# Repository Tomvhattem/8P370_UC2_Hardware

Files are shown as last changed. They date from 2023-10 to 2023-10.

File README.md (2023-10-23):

# 8P370_UC2_Hardware
This Repository contains several new files and adjusted files made for the UC2 System and the openflexure delta stage for use in the CBL Microscopy course at the TU/e at the courtesy of N4N Group. For questions you can email me at: t.c.v.hattem@student.tue.nl

## Credits and useful links
These adaptation are based on the original files of two open source project UC2 and Openflexure, please check out their respective websites for more information.

- **UC2 Hardware**: Original ImSwitch.
  - Repository: [UC2 General GitHub Repository](https://github.com/openUC2/UC2-GIT)
  - Website: [UC2 Website](https://openuc2.com/)

- **Openflexure Hardware**: .
  - Website: [Openflexure Website]([https://openuc2.com/](https://openflexure.org/))

- **N4N Lab**: Supporting Research Group
  - Website: [n4nlab.eu](https://www.n4nlab.eu/)

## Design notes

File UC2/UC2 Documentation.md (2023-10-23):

# UC2 Add-ons and Custimizations

### Z-Stage
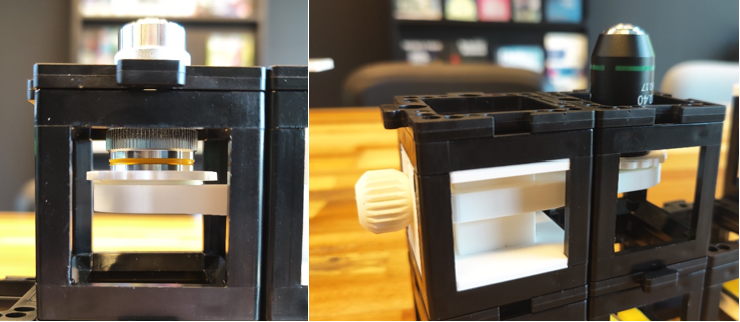
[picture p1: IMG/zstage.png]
 <br>
The original Z-stage https://github.com/openUC2/UC2-GIT/tree/master/CAD/ASSEMBLY_CUBE_Z-STAGE_mechanical is relatively prone to breaking. The manual knob was often very hard to use, therefore the z-stage was redesigned. It requires 2 cubes of space and has two adjustments. A large rough adjustment, by sliding the whole part up or down and tightening with the knob. The objective lense is screwed into a printed screw. The printed part can be rotated for fine adjustments. Printing in ABS has nicer tolerances, especially for the screw part. A combination of all PLA but screw in ABS or the other way around also works nicely. 
With the redesigned manual Z-stage a simple smartphone microscope is built for verification. See https://uc2configurator.netlify.app/ APP_SIMPLE-Smartphone_Microscope <br>

#Heat Inserts
Heat inserts make sure that you can tighten the design for more than once, when only using abs or pla it can quickly be overturned. To ensure longevity of the design heat inserts are used.
Never used heat inserts? Then continue reading… The screw hole at the red arrow in figure 5 is designed for an brass heat insert. 
The brass heat inserts can be pushed into the design from outside into the print with a soldering iron. Makes sure that the insert is straight, you can make sure it is by inserting a long bolt and reapplying heat and straightening the bolt. 
M3 heat inserts are used. They exist in several lengths, they should not be longer than 5.5 [mm]. The Hole is a little bit larger 3.5mm to make sure they fit but do not have excess material pushed into the design. It should be flush with the outside of the print. <br>

<div style="display: flex;">
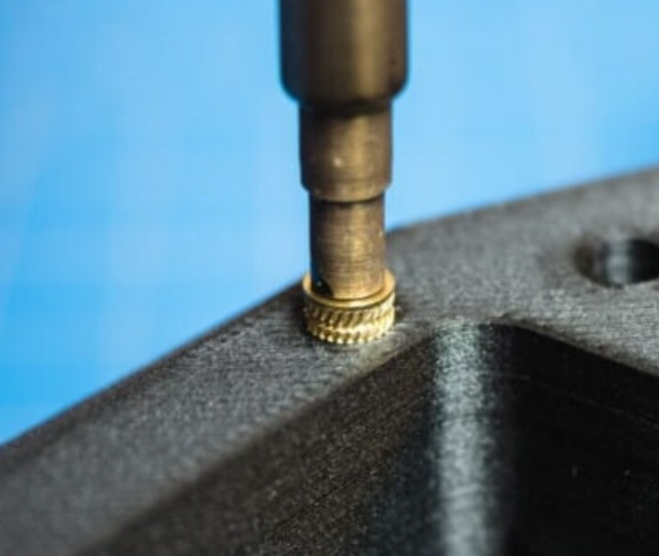
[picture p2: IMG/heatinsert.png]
Heat Insert
    
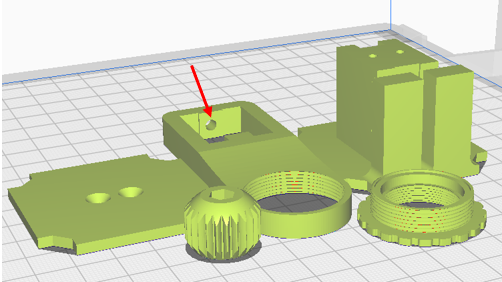
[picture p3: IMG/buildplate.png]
    
</div>

## Insert for Light-Sensitive Setups:
The light-sensitive setup includes a specialized insert designed to block external light sources and prevent light leakage during fluorescence microscopy. Open the cube to insert the 3d printed part. This was designed and tested with ABS, PLA results may vary due to different tolerances. Also depends on the used setup and printer. 

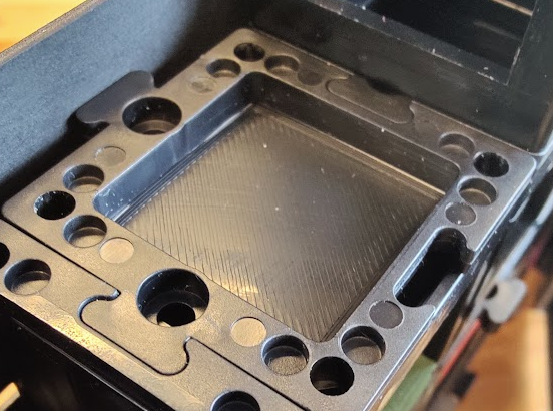
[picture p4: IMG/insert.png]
Insert


## Cardboard Enclosure
The microscope setup includes a custom cardboard enclosure that provides protection and stability for the components. Follow the instructions below for cutting and assembling the cardboard enclosure:

### Assembly Steps:
1. **Cutting the Cardboard:**
   - Depending on your setup measure and draw out the different pieces required to enclose your setup.
   - Ensure precise cutting for accurate fitting of the enclosure components.

2. **Corner Piece Connection:**
   - Use the 3D printed corner pieces to connect the cardboard panels securely.
   - Align the corner pieces with the corresponding corners of the cardboard pieces.
   - Insert the cardboard edges into the slots of the corner pieces.

3. **Setup the Microscope:**
   - Place the microscope inside the assembled cardboard enclosure, ensuring it fits snugly and is properly centered. It might be required to first insert the microscope setup while assembling the cardboard pieces.

4. **Use inserts in critical places:**
   - The insert cover discussed in the previous paragraph might be required in the inside of the microscope since the setup often requires sample and laser to be quite close. 

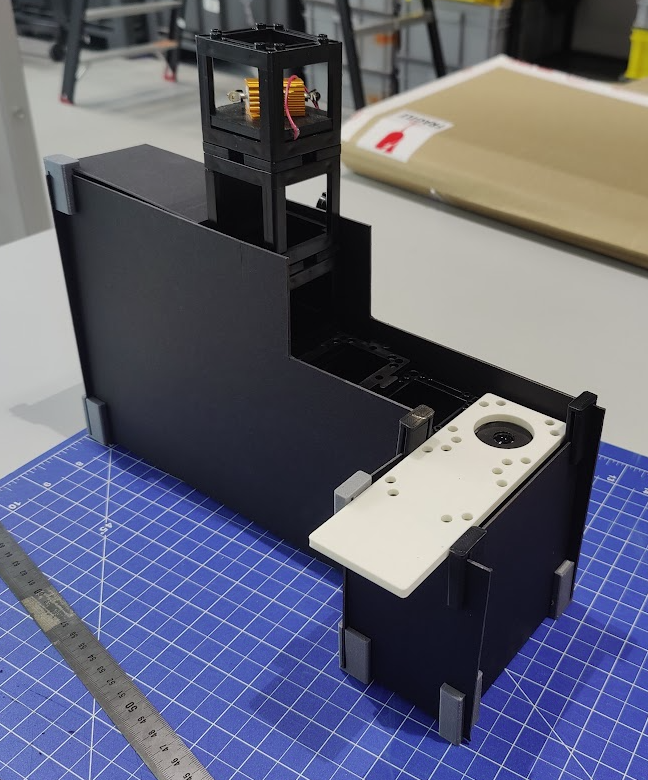
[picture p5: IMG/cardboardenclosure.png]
cardboard Enclosure


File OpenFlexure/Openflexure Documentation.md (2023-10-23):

# Openflexure Documentation

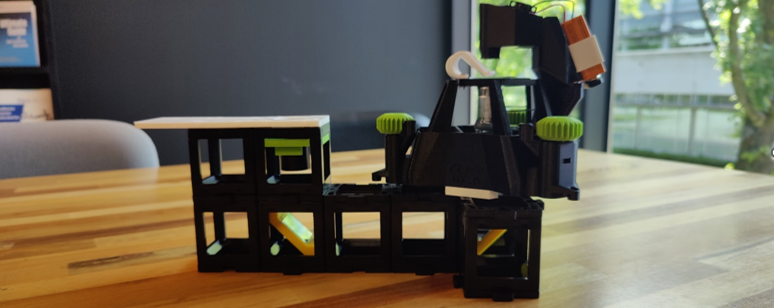
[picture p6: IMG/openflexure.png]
Heat Insert


Mechanical version of the delta stage with tweaks for better usability. The original version requires feet and rubber bands to force the stage down. This is not required but recommmended! In combination with the UC2 cubes the feet do not fit, so an smaller adjusted version was made. The delta stage can be used in combination with the UC2 system. On the bottom an (now adjusted) connector part is used. For the main unit it is important to print without an brim! There is a version with a smart brim built into the file, this works too. (See openflexure.org) <br>

 There are 2 options: using the original LED module, adjusted to hold a 9V battery or using UC2 cubes on top. Make sure not to add too many cubes on top as vibrations could become an issue. <br>

# Part List

## Manual Mechanical Version:
This folder contains STL files for the manual mechanical version of the project. These files include components designed for manual operation, with redesigned knobs for easier use. Print these files for the non-motorized version of the project.
- `delta_stage_remaster.stl`
- `feet_lowprofile_uc2.stl`
- `Knob [3x].stl`
- `OpticalLense_Adapter_CUSTOM.stl`
- `OpticalLense_Adapter.stl`
- `Small_Knob.stl`

## Motorized Version:
This folder contains STL files for the motorized version of the project. These files are designed to be used with motors for automated operation. Ensure proper assembly and alignment of motorized components for optimal functionality.
- `delta_stage_remaster.stl`
- `feet_lowprofile_uc2.stl`
- `Knob [3x].stl`
- `large_gears.stl`
- `OpticalLense_Adapter_CUSTOM.stl`
- `OpticalLense_Adapter.stl`
- `Small_Knob.stl`
- `Small_gears.stl`

## UC2 Connection:
This folder contains files related to the connection between the Delta Stage and UC2 blocks. These components ensure a secure and stable connection between these elements.
- `UC2-Bottom-Connector.stl`
- `UC2-Top-Connector.stl`

## Optional Parts:
This folder contains additional optional components that can be used based on specific project requirements.

- **Actuator Assembly Tools:**
  - **File:** `Actuator_assembly_tools.stl`
  - **Description:** Tools designed to assist in the assembly rubber bands, see openflexure.org deltastage manual for more tips.
- **LED Components:**
  - **File:** `LED_9vClip_plain.stl`
  - **File:** `LED_condensor.stl`
  - **File:** `LED_illumination_dovetail.stl`
  - **Description:** These files represent various components related to LED illumination in the project. Use them as needed for your specific lighting requirements.
- **Sample Clips:**
  - **File:** `sample_clips.stl`
  - **Description:** Clips designed for specific applications within the project. Use them for securing components as required.

## Printing and Assembly Instructions:
Please follow these guidelines for 3D printing and assembly:

1. **3D Printing:**
   - Use PLA or ABS filament based on your preference and printer compatibility. For components directly used with a lense, such as `OpticalLense.stl` parts, print in Black. 
   - Ensure proper bed adhesion and avoid warping issues during printing.
   - Print with support for intricate parts as needed.

2. **Assembly:**
   - Carefully assemble the components, ensuring precise alignment.
   - For the motorized version, integrate motors according to the provided motor mounting guidelines.
   - Lubricate moving parts if necessary for smooth operation.
   - Verify that all components fit together securely.

## Notes:
- Verify the compatibility of motorized components with your chosen motors and power supply.
- Test the functionality of moving parts and connections before finalizing the assembly.
- For any questions or issues, refer to the project documentation or contact the project team for assistance.

## Change Log:
- Redesigned main knobs for easier mechanical use.
- Added fourth knob for adjustable objective lens height, eliminating the need for screwdrivers. Improved grip for precise adjustments.
- Adjusted main stage for smooth movement of the fourth knob, especially when using the delta stage with the extra part for the simple LED module.
- Designed a battery holder for the simple LED module, manually glued with plastic glue for better orientation. Use white LED.
- Modified tolerance of UC2 and Delta Stage adapter holes in PLA for a better fit (tried ABS but faced inconsistent warping). Outer parts are slightly loose to prevent excess tension on the cubes. Print with support and the largest part on the bottom.
- Created UC2 delta stage adapter for the top part.
- Adjusted objective lens height due to the added UC2 Delta Stage adapter height. Nut placement shifted to the bottom. Enhanced moveability in the Delta stage itself. Original LED module attachment is optional. Knobs for motors are retained but unused.

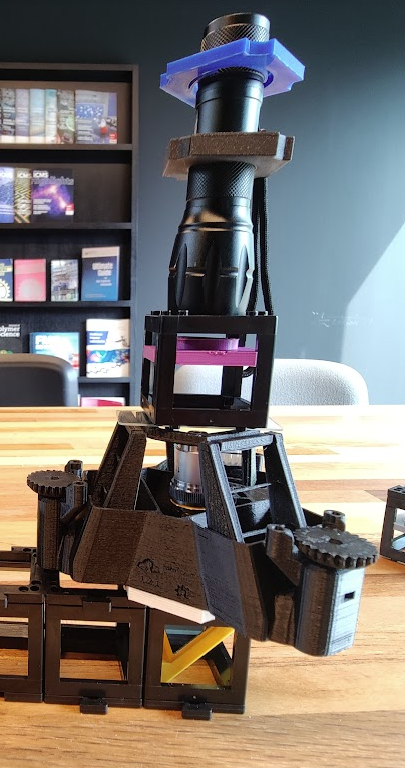
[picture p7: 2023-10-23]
IMG/openflexure2.png

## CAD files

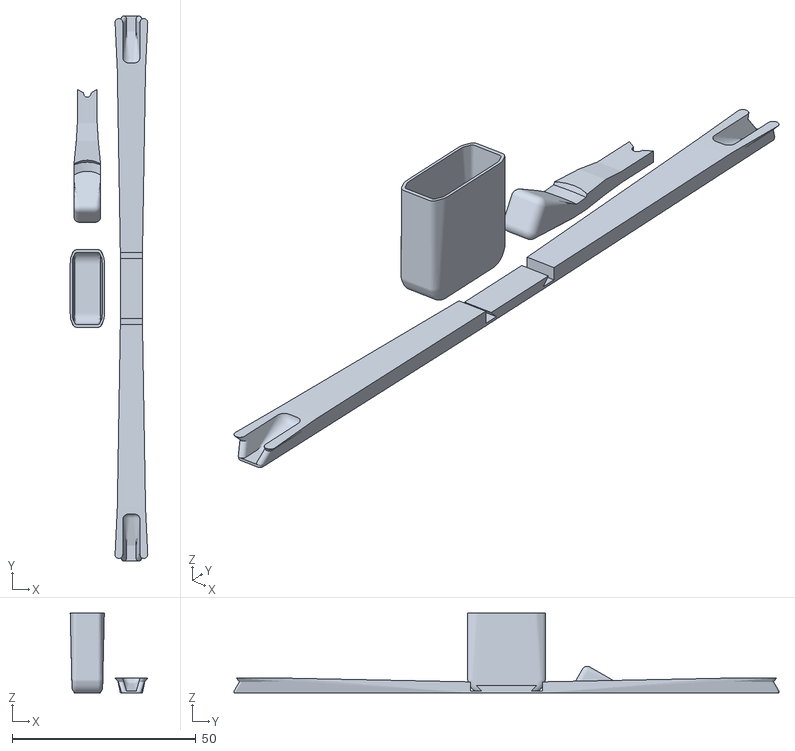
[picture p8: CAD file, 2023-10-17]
OpenFlexure/STL/Optional/OPTIONAL_actuator_assembly_tools.stl
21.1 x 148.2 x 21.7

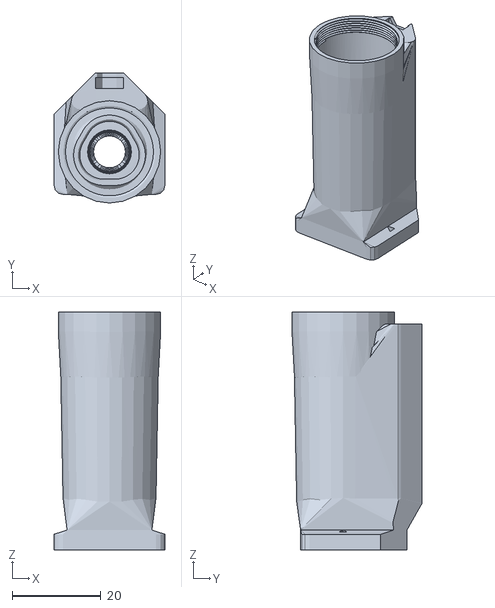
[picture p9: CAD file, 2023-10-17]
OpenFlexure/STL/Mechanical/OpticalLense_Adapter_CUSTOM.stl
25.0 x 29.3 x 53.7

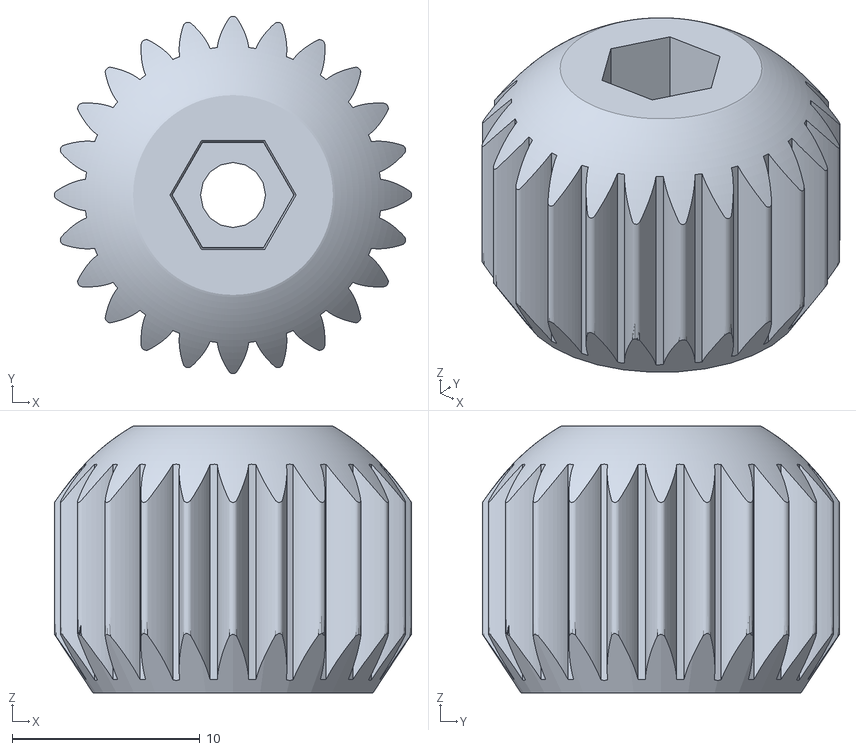
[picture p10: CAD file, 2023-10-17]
OpenFlexure/STL/Motorized/Small_Knob.stl
19.0 x 19.0 x 14.2

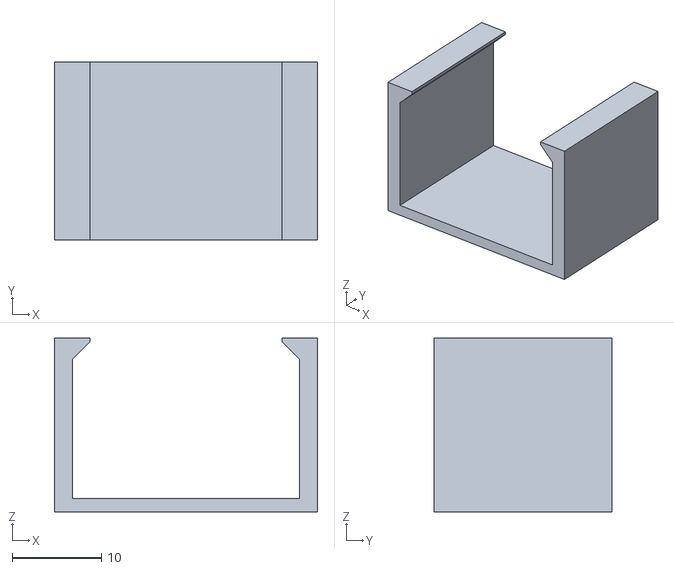
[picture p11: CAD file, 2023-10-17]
OpenFlexure/STL/Optional/OPTIONAL_LED_9vClip_plain.stl
29.5 x 20.0 x 19.5

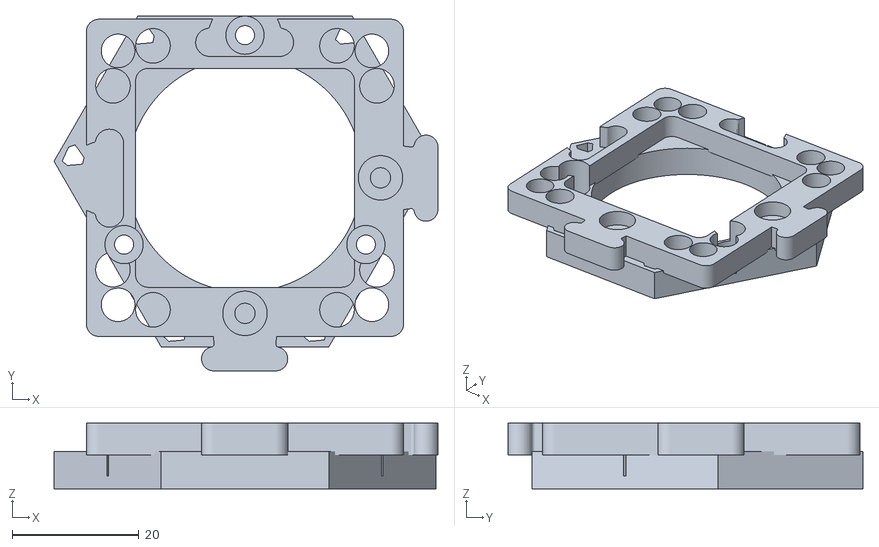
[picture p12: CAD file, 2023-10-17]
OpenFlexure/STL/UC2 Connection/UC2-Top-Connector.stl
60.5 x 55.9 x 10.3

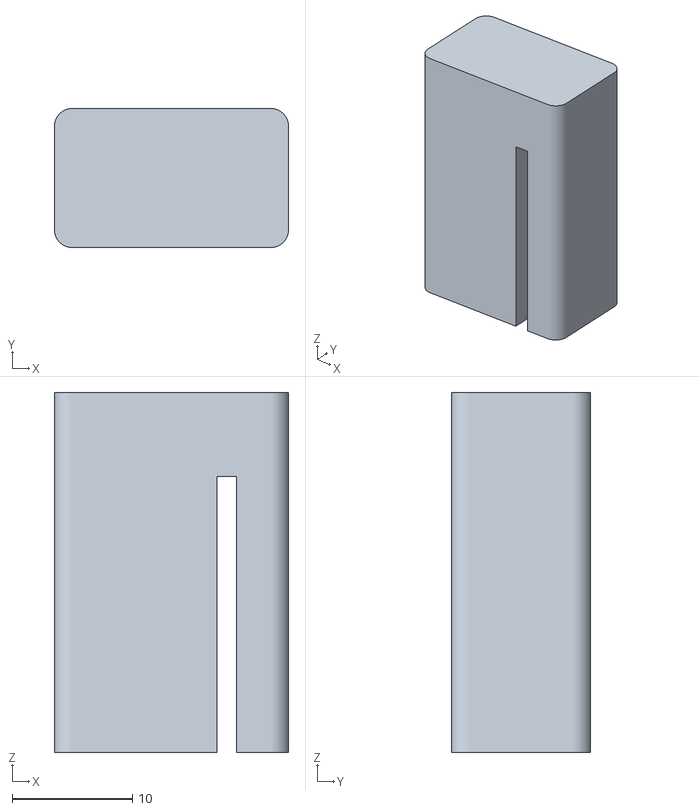
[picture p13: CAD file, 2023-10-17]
UC2/Cardboard Enclosure/CornerPiece_CardboardEnclosure.stl
19.5 x 11.6 x 30.0

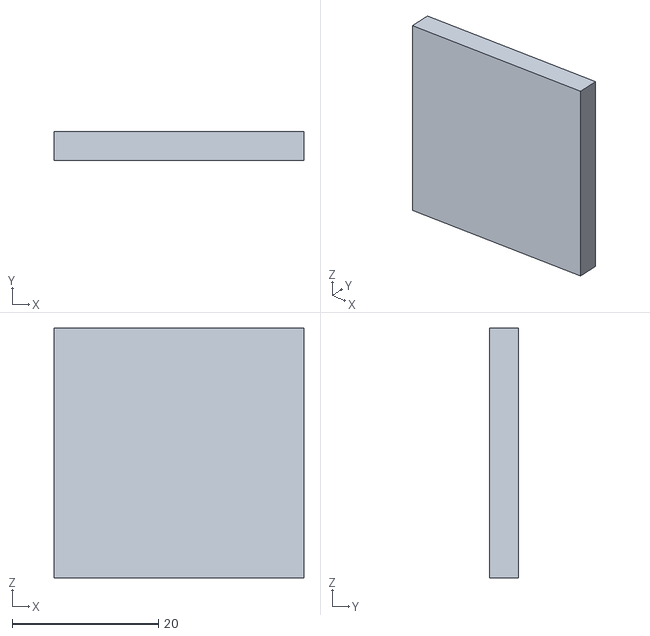
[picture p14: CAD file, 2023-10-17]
UC2/Cube Inserts/UC2-Block_Side_Cover.stl
34.2 x 3.92 x 34.2

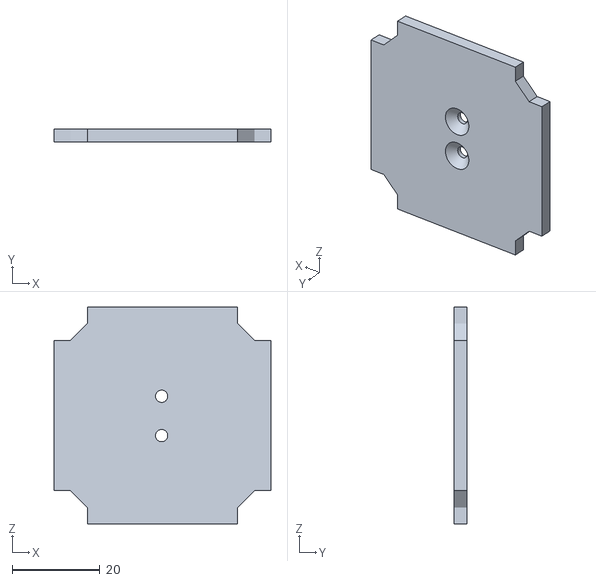
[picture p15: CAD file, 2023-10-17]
UC2/Mechanical_Z-Stage/TopPlate.stl
49.6 x 3.00 x 49.6

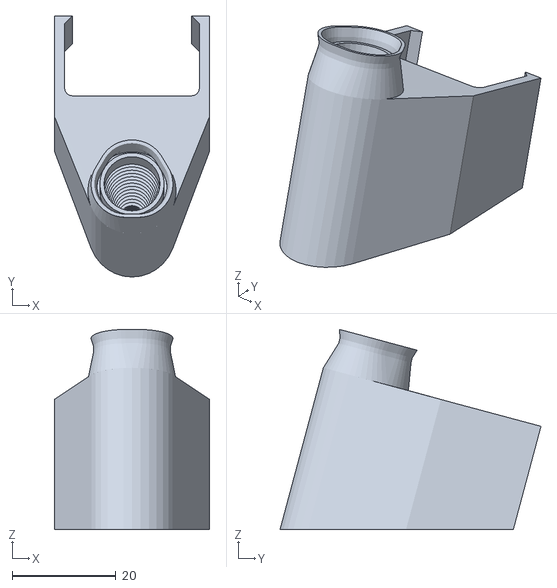
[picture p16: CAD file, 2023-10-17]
OpenFlexure/STL/Optional/OPTIONAL_LED_condenser.stl
30.0 x 50.4 x 38.6

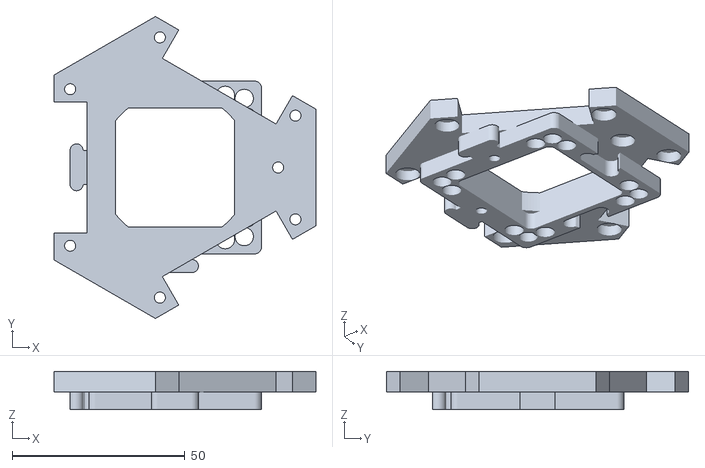
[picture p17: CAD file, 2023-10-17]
OpenFlexure/STL/UC2 Connection/UC2-Bottom-Connector.stl
75.7 x 87.4 x 11.0

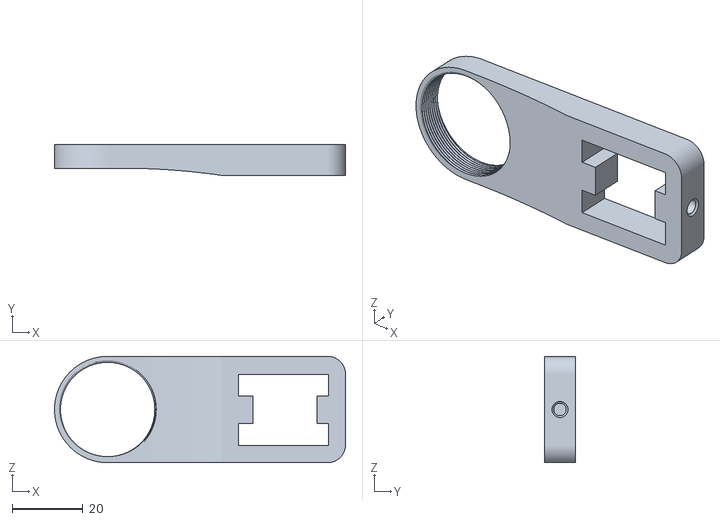
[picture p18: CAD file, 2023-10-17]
UC2/Mechanical_Z-Stage/Slider2.stl
82.1 x 8.66 x 30.0

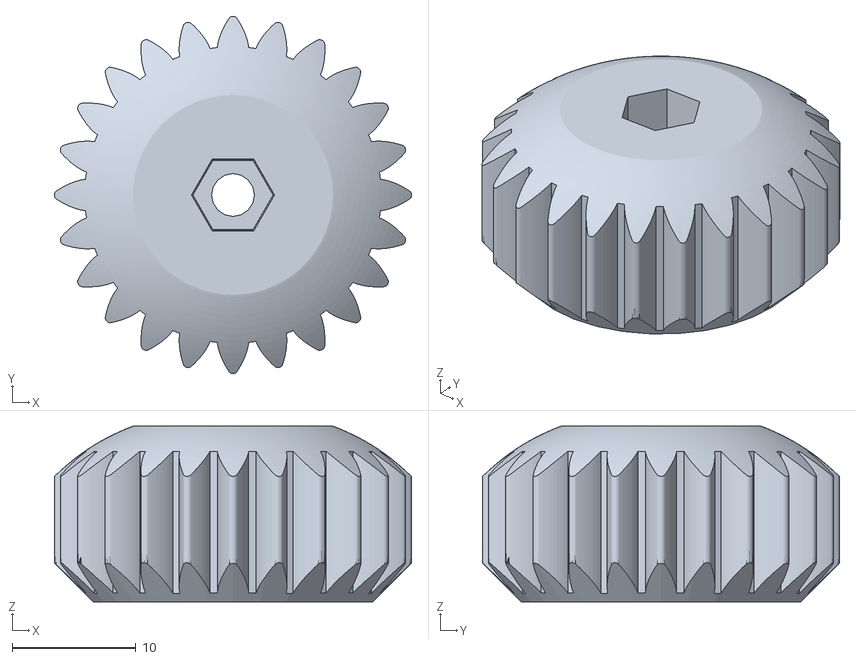
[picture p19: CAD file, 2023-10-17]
OpenFlexure/STL/Mechanical/Knob [3x].stl
28.9 x 28.9 x 14.2

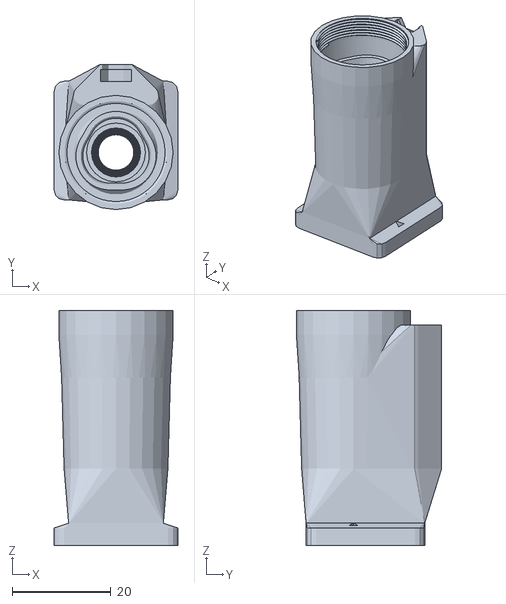
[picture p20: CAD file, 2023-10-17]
OpenFlexure/STL/Motorized/OpticalLense_Adapter.stl
25.0 x 29.4 x 47.5

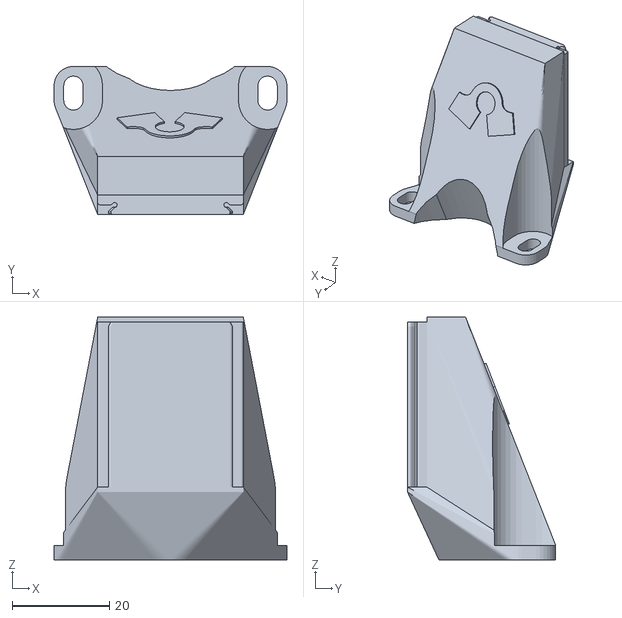
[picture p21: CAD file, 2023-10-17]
OpenFlexure/STL/Optional/OPTIONAL_LED_illumination_dovetail.stl
48.0 x 30.5 x 50.0

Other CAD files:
UC2/Mechanical_Z-Stage/Base.stl
OpenFlexure/STL/Mechanical/delta_stage_remaster.stl
OpenFlexure/STL/Mechanical/feet_lowprofile_UC2.stl
OpenFlexure/STL/Motorized/delta_stage_remaster.stl
OpenFlexure/STL/Motorized/feet_lowprofile_UC2.stl
OpenFlexure/STL/Motorized/large_gears.stl
OpenFlexure/STL/Motorized/small_gears.stl
OpenFlexure/STL/Optional/OPTIONAL_sample_clips.stl
UC2/Mechanical_Z-Stage/FineAdjustments.stl
UC2/Mechanical_Z-Stage/FineAdjustments2.stl
UC2/Mechanical_Z-Stage/Slider.stl

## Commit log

2023-10-17 STL Files
    [Base.stl, CornerPiece_CardboardEnclosure.stl, FineAdjustments.stl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]
2023-10-23 Side cover and cardboard images
    [CornerPiece_CardboardEnclosure.stl, UC2-Block_Side_Cover.stl]
2023-10-23 insert and cardboard enclosure documentation text.
